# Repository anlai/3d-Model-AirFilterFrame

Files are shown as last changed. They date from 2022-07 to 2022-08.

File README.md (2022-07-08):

# Parametric Air Filter Frame

This project is a OpenSCAD parametric Air Filter Frame.  It's a design for a frame that can be filled with either HEPA filter medium or activated carbon to be used in air filters.

The frame is originally designed to be used in conjunction with the [AirManagerV2](https://www.printables.com/model/16996-airmanagerv2-recirculating-air-filter-for-3d-print), either as a whole frame insert, create your own HEPA and carbon set, or a carbon filter to go with another purchased HEPA filter.  The filter set suggested wit the AirManagerV2 is hard to source in the US, however there are several close HEPA filters in size (but don't have a matching carbon filter) and are smaller than the whole device.

This project generates two main components: 1) Filter Spacer 2) Air Filter Frame (top and bottom), each of these are parameterized as much as possible to allow for you to generate ones of different sizes.  It's not required to use it with the AirManagerV2, but that's what dimensions it uses as the default values.

## Filter Spacer

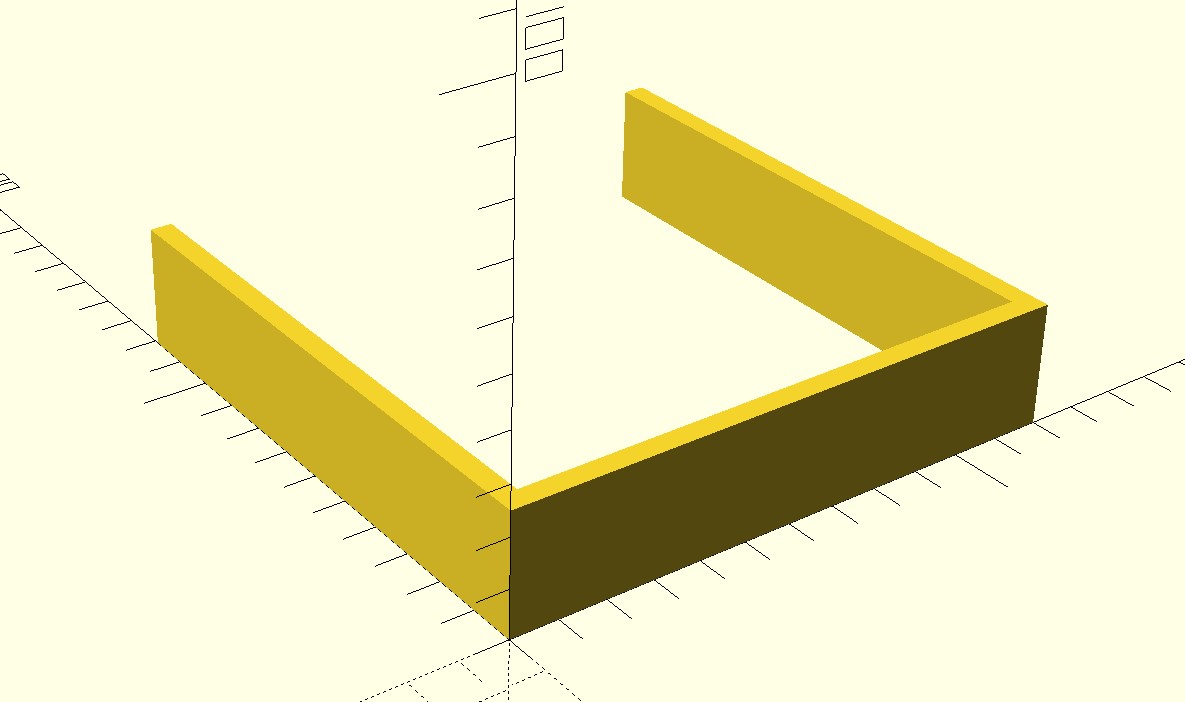
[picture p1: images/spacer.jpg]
spacer image


The spacer is meant to help make a smaller filter fit into the AirManagerV2 (or any other filter holder) and keep it centered.  The default dimensions of 120x120x26mm for the scad file are the interior dimensions of the AirManagerV2 filter compartment.

For example if you buy a HEPA filter measuring 110x110x15mm, you'll get a spacer to fit three sides that will measure 10mm thick and 26mm tall (height of the compartment).

## Filter Frame

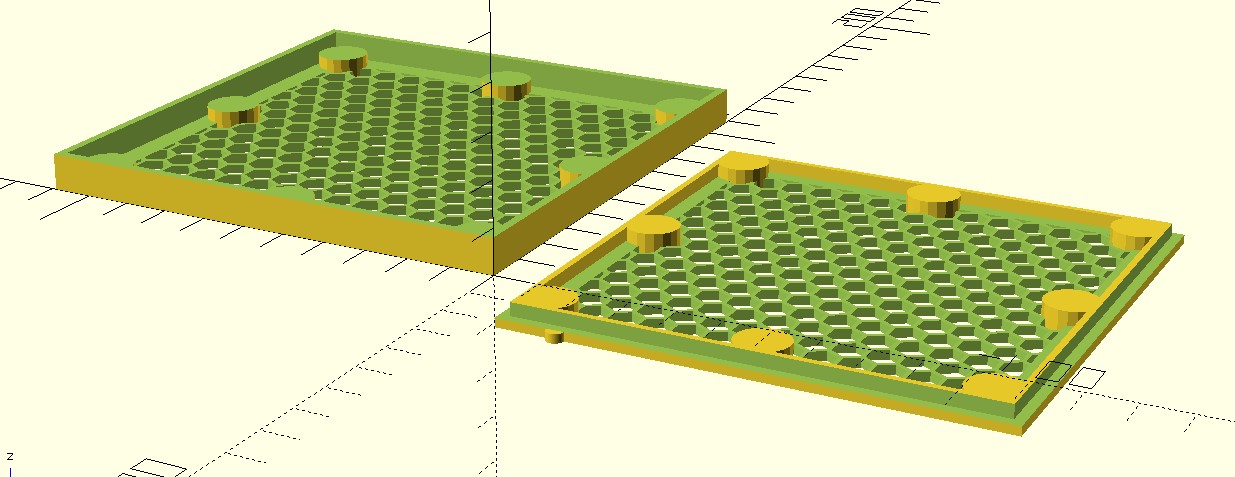
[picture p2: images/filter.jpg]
filter frame image


The filter frame is composed of two parts a top and a bottom and held together by 8 pairs of magnets (probably overkill) which are embedded in the cylinders about 1.5mm from the surface.  I purchased 10x2mm magnets which work out fine but you can adjust the size of the magnets your purchase in the parameters.

The size of the frame can be created by 1 of ways: 1) remaining space from a HEPA filter 2) custom size

### Remaining Space Sizing

This method essentially creates a matching carbon cartridge to a HEPA filter you purchase and uses the remaining space in the compartment to determine size.  This method will be used as long as all the dimensions prefixed with "custom_filter_*" are left at -1.

For example, given the compartment dimensions of 120x120x26mm and a HEPA filter size of 110x110x15mm.  It will create a filter frame the size of 110x110x11mm, which can then be filled with activated carbon to make a set.

### Custom Sizing

This method will create a filter frame of the size of your choosing.  Either creating a single frame to be filled with all carbon, or you can make two matching frames and fill one with filter material and the other with carbon.

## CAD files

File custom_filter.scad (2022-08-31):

/* [rendering] */
// render the filter spacer
render_spacer=false;
// render the filter cartridge
render_filter=false;
// render the filter cartridge top
render_filter_top=false;

render_ghost=false;

/* [filter housing dimensions] */
// interior width of the box (side to side)
box_width = 120;
// interior depth of the box (front to back)
box_depth = 120;
// interior height of the box
box_height = 26;

/* [hepa filter dimensions] */
// hepa filter width
hepa_width = 109;
// hepa filter depth
hepa_depth = 109;
// hepa filter height
hepa_height = 15;

/* [custom filter settings] */

// custom filter width
custom_filter_width = -1;

// custom filter depth
custom_filter_depth = -1;

// custom filter_height
custom_filter_height = -1;

// filter wall thickness
filter_wall_thickness = 2;

// filter grid frame thickness
filter_frame_thickness = 15;

// multiplier on grid sizing
filter_frame_multiplier = .2;

// magnet holders in corners
filter_magnets_corners = true;

// magnet holders in the middle
filter_magnets_middle = true;

// space in the bottom for magnetic feet (follows corners/middle settings)
filter_magnets_feet = true;

// diameter of magnet being insert
filter_magnet_diameter = 10;

// height of magnet being insert
filter_magnet_height = 1;

// carbon cavities
filter_carbon_cavities = true;

/* [spacer settings] */
// fudge factor for spacer
fudge = 1;

/* [hidden] */
// filter calculated measurements
filter_width = custom_filter_width>0 ? custom_filter_width : hepa_width;
filter_depth = custom_filter_depth>0 ? custom_filter_depth : hepa_depth;
filter_height = custom_filter_height>0 ? custom_filter_height : box_height-hepa_height;

// magnet location calculations
magnet_offset = (filter_wall_thickness*.5+filter_magnet_diameter/2);
magnet_locations_corners = [
    // corners
    [magnet_offset+filter_wall_thickness, magnet_offset+filter_wall_thickness],
    [filter_width-magnet_offset-filter_wall_thickness, magnet_offset+filter_wall_thickness],
    [magnet_offset+filter_wall_thickness,filter_depth-magnet_offset-filter_wall_thickness],
    [filter_width-magnet_offset-filter_wall_thickness,filter_depth-magnet_offset-filter_wall_thickness],
];
magnet_locations_middles = [
    // centers
    [filter_width/2, magnet_offset+filter_wall_thickness],
    [filter_width/2, filter_depth-magnet_offset-filter_wall_thickness],
    [magnet_offset+filter_wall_thickness, filter_depth/2],
    [filter_width-magnet_offset-filter_wall_thickness, filter_depth/2]
];
magnet_cover_thickness=1.5;

module custom_filter() {
    cavity_offset = 2*filter_wall_thickness;

    difference(){
        // shell
        cube([filter_width, filter_depth, filter_height]);

        // cut out the center cavity
        translate([filter_wall_thickness, filter_wall_thickness, filter_wall_thickness]){
            cube([filter_width-cavity_offset, filter_depth-cavity_offset, filter_height-cavity_offset]);
        }

        // cut out the grid holes
        translate([filter_width/2,filter_depth/2,filter_height/2+1]){
            invert_grid(filter_width-filter_frame_thickness, filter_depth-filter_frame_thickness,filter_height+4,filter_frame_multiplier);
        }
    }

    // add supports for magnets
    if(filter_magnets_corners) {
        for (coord = magnet_locations_corners)
            custom_filter_magnet_support(coord.x, coord.y);
    }

    if (filter_magnets_middle) {
        for (coord = magnet_locations_middles)
            custom_filter_magnet_support(coord.x, coord.y);
    }

    // add the fill on the inside for the carbon pieces
    if (filter_carbon_cavities)
    {
        translate([filter_wall_thickness, filter_wall_thickness, filter_wall_thickness]){
            difference() {
                color("blue") cube([filter_width-cavity_offset, filter_depth-cavity_offset, filter_height-cavity_offset-1]);

                carbon_holder_diameter=20;//5;
                carbon_holder_spacing=.5;
                carbon_holder_count=3;//18;
                carbon_holder_initial_offset=(carbon_holder_diameter/2)+filter_magnet_diameter+(2*fudge); //carbon_holder_diameter/2+carbon_holder_spacing;

                translate([carbon_holder_initial_offset,carbon_holder_initial_offset,0])
                for(i = [0:carbon_holder_count])
                for(j = [0:carbon_holder_count])
                    translate([i*(carbon_holder_diameter+carbon_holder_spacing),j*(carbon_holder_diameter+carbon_holder_spacing),0])
                cylinder(d=carbon_holder_diameter,h=filter_height-cavity_offset,$fn=360);
            }
        }        
    }
}

// interior supports for the magnets
module custom_filter_magnet_support (x_offset,y_offset) {
    // height of the cylinder only on the interior of the filter
    cylinder_height = filter_height;
    cylinder_diameter = filter_magnet_diameter+(2*fudge);

    // render the cylinder
    translate([x_offset,y_offset]) {
        cylinder(h=cylinder_height,d=cylinder_diameter);        
    }
}

// hole for the magnet
module magnet_cavity(x_offset,y_offset,z_offset){
    translate([x_offset,y_offset,z_offset])
        cylinder(h=filter_magnet_height+fudge,d=filter_magnet_diameter+fudge);
}

// invert the grid so the holes cut out from the shell
module invert_grid(width,depth,height,frame_hole_multiplier) {
    difference(){
        cube([width, depth, height], true);
        translate([0,0,-1])
        grid(width+10, depth+10, gridThickness=height+1,sizeMultipler=frame_hole_multiplier);
    }
}

module grid(width=193,depth=88,roundness=4.5,gridThickness=5,sizeMultipler=1) {
    grid_gap = 0.5;
    
    border = 1.7;
    hex_d =  14*sizeMultipler; //7;//14;
    
    x_sep =  10.5*sizeMultipler; //5.25;//10.5;
    y_sep = 0;
    
    x_shift = x_sep + hex_d;
    y_shift = y_sep + hex_d;
    
    hlf_width = width/2;
    hlf_depth = depth/2;
    
    edgeOffset = (gridThickness-2)*.5;
    
    // outer edge
    translate([0,0,-edgeOffset])
    difference() {
        round_cube([width-grid_gap*2, depth-grid_gap*2, gridThickness], roundness-1, $fn=40);
        translate([0,0,-1])
        round_cube([width-grid_gap*2-border*2, depth-grid_gap*2-border*2, gridThickness*2], roundness-1, $fn=40);
    }
    
    
    difference() {
        translate([0,0,1])
        cube([width-grid_gap*2-border*2, depth-grid_gap*2-border*2, gridThickness], center=true);
        
        x_steps = floor((hlf_width - border/2) / x_shift);
        y_steps = floor(hlf_depth / y_shift);
        
        for(x = [-x_steps : x_steps],
            y = [-y_steps : y_steps]) {
        
            translate([x_shift*x,y_shift*y,0])
            cylinder(d=hex_d, h=gridThickness*3, center=true, $fn=6);
        }
        
        alt_x_steps = floor((hlf_width - x_shift/2 - border/2) / x_shift);
        alt_y_steps = floor((hlf_depth - y_shift/2) / y_shift);
        
        for(x = [ -alt_x_steps - 1 : alt_x_steps ],
            y = [ -alt_y_steps - 1 : alt_y_steps ]) {
        
            translate([x_shift*x,y_shift*y,0])
            translate([x_shift/2,y_shift/2,0])
            cylinder(d=hex_d, h=gridThickness*3, center=true, $fn=6);
        }
    }
}

module round_cube(coords, r=0) {
        
    if (r<=0) {
        translate([0,0,coords[2]/2])
        cube(coords, center=true);
    } else {
        x = coords[0];
        y = coords[1];
        z = coords[2];
        hull() {
            translate([ x/2 - r,  y/2 - r]) cylinder(r=r, h=z);
            translate([-x/2 + r,  y/2 - r]) cylinder(r=r, h=z);
            translate([ x/2 - r, -y/2 + r]) cylinder(r=r, h=z);
            translate([-x/2 + r, -y/2 + r]) cylinder(r=r, h=z);
        }

    }   
}

// separates the top
module custom_filter_top_cutout(additionalMagnetSupportDiameter=0) {
    translate([0,0,filter_height-filter_wall_thickness]){
        cube([filter_width,filter_depth,filter_height]);
    }

    // add supports for magnets
    if (filter_magnets_corners){
        for (coord = magnet_locations_corners)
            custom_filter_top_magnet_support(coord.x, coord.y, additionalMagnetSupportDiameter);
    }

    if (filter_magnets_middle) {
        for (coord = magnet_locations_middles)
            custom_filter_top_magnet_support(coord.x, coord.y, additionalMagnetSupportDiameter);
    }
}

module custom_filter_top_magnet_support(x_offset,y_offset,additionalMagnetSupportDiameter) {
    cylinder_height = filter_magnet_height+fudge+(2*magnet_cover_thickness);
    cylinder_diameter = filter_magnet_diameter+(2*fudge)+additionalMagnetSupportDiameter;

    translate([x_offset,y_offset,filter_height-cylinder_height])
        cylinder(h=cylinder_height,d=cylinder_diameter);
}

// spacer that goes full depth front to back
module depth_spacer() {
    spacer_width = ((box_width-hepa_width)/2)-fudge;
    spacer_depth = box_depth-fudge;
    spacer_height = box_height-fudge;

    cube([spacer_width, spacer_depth, spacer_height]);
}
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

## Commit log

2022-06-27 initial commit of models
    [custom_filter.scad, grid.scad]
2022-07-07 added lip around the top
    [custom_filter.scad]
2022-07-08 added a tab for the top
    [custom_filter.scad]
2022-08-31 carbon filter compartments
    [custom_filter.scad, grid.scad]
